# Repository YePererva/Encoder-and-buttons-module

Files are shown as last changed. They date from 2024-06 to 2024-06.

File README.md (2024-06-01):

# Rotary encoder and Push-Buttons module with hardware debouncing

Module provides rotary encoder and 3 push-buttons with debouncing circuitry, based on 74xx14 inverting Schmitt trigger.

## Dimensions and layout

- overall dimensions: 1.0 in × 2.5 in
- mounting holes spacing : 0.75 in × 2.25 in
- mounting holes size : M3
- SMD sized:
	- Resistors: 0805
	- Capacitors : 0805
	- Diodes : MiniMELF

| Top View | Bottom View |
| --- | ---|
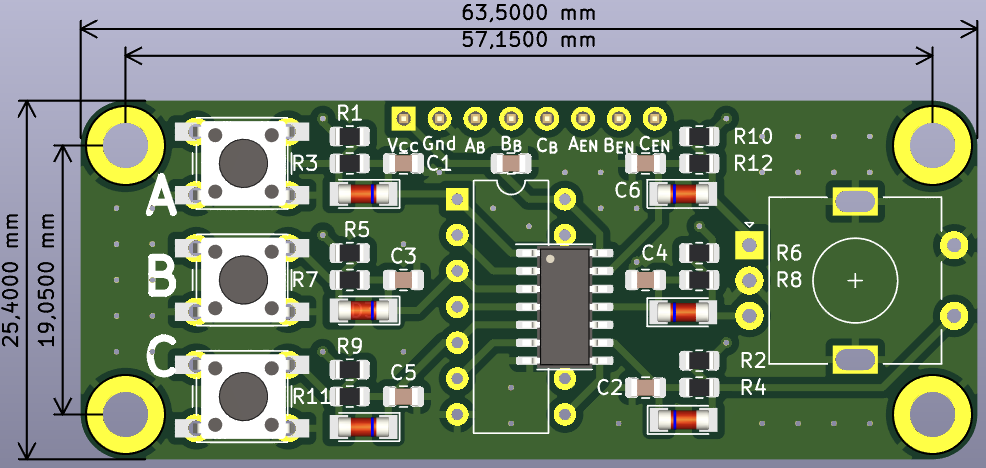
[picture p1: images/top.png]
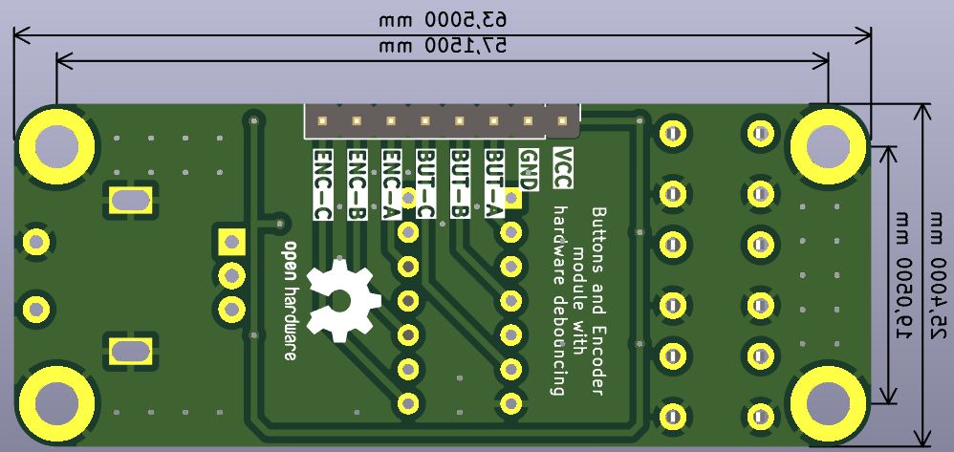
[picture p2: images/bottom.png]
|  |  |

## Schematics origin

Schematics is based on [this](https://my.eng.utah.edu/~cs5780/debouncing.pdf) work and is adjusted for:
- having both 1 rotary incremental encoder and 3 push buttons
- ability to solder eitehr SMD or DIP version of 74xx14 IC
- having option to push into breadboard or mount somewhere via mounting holes

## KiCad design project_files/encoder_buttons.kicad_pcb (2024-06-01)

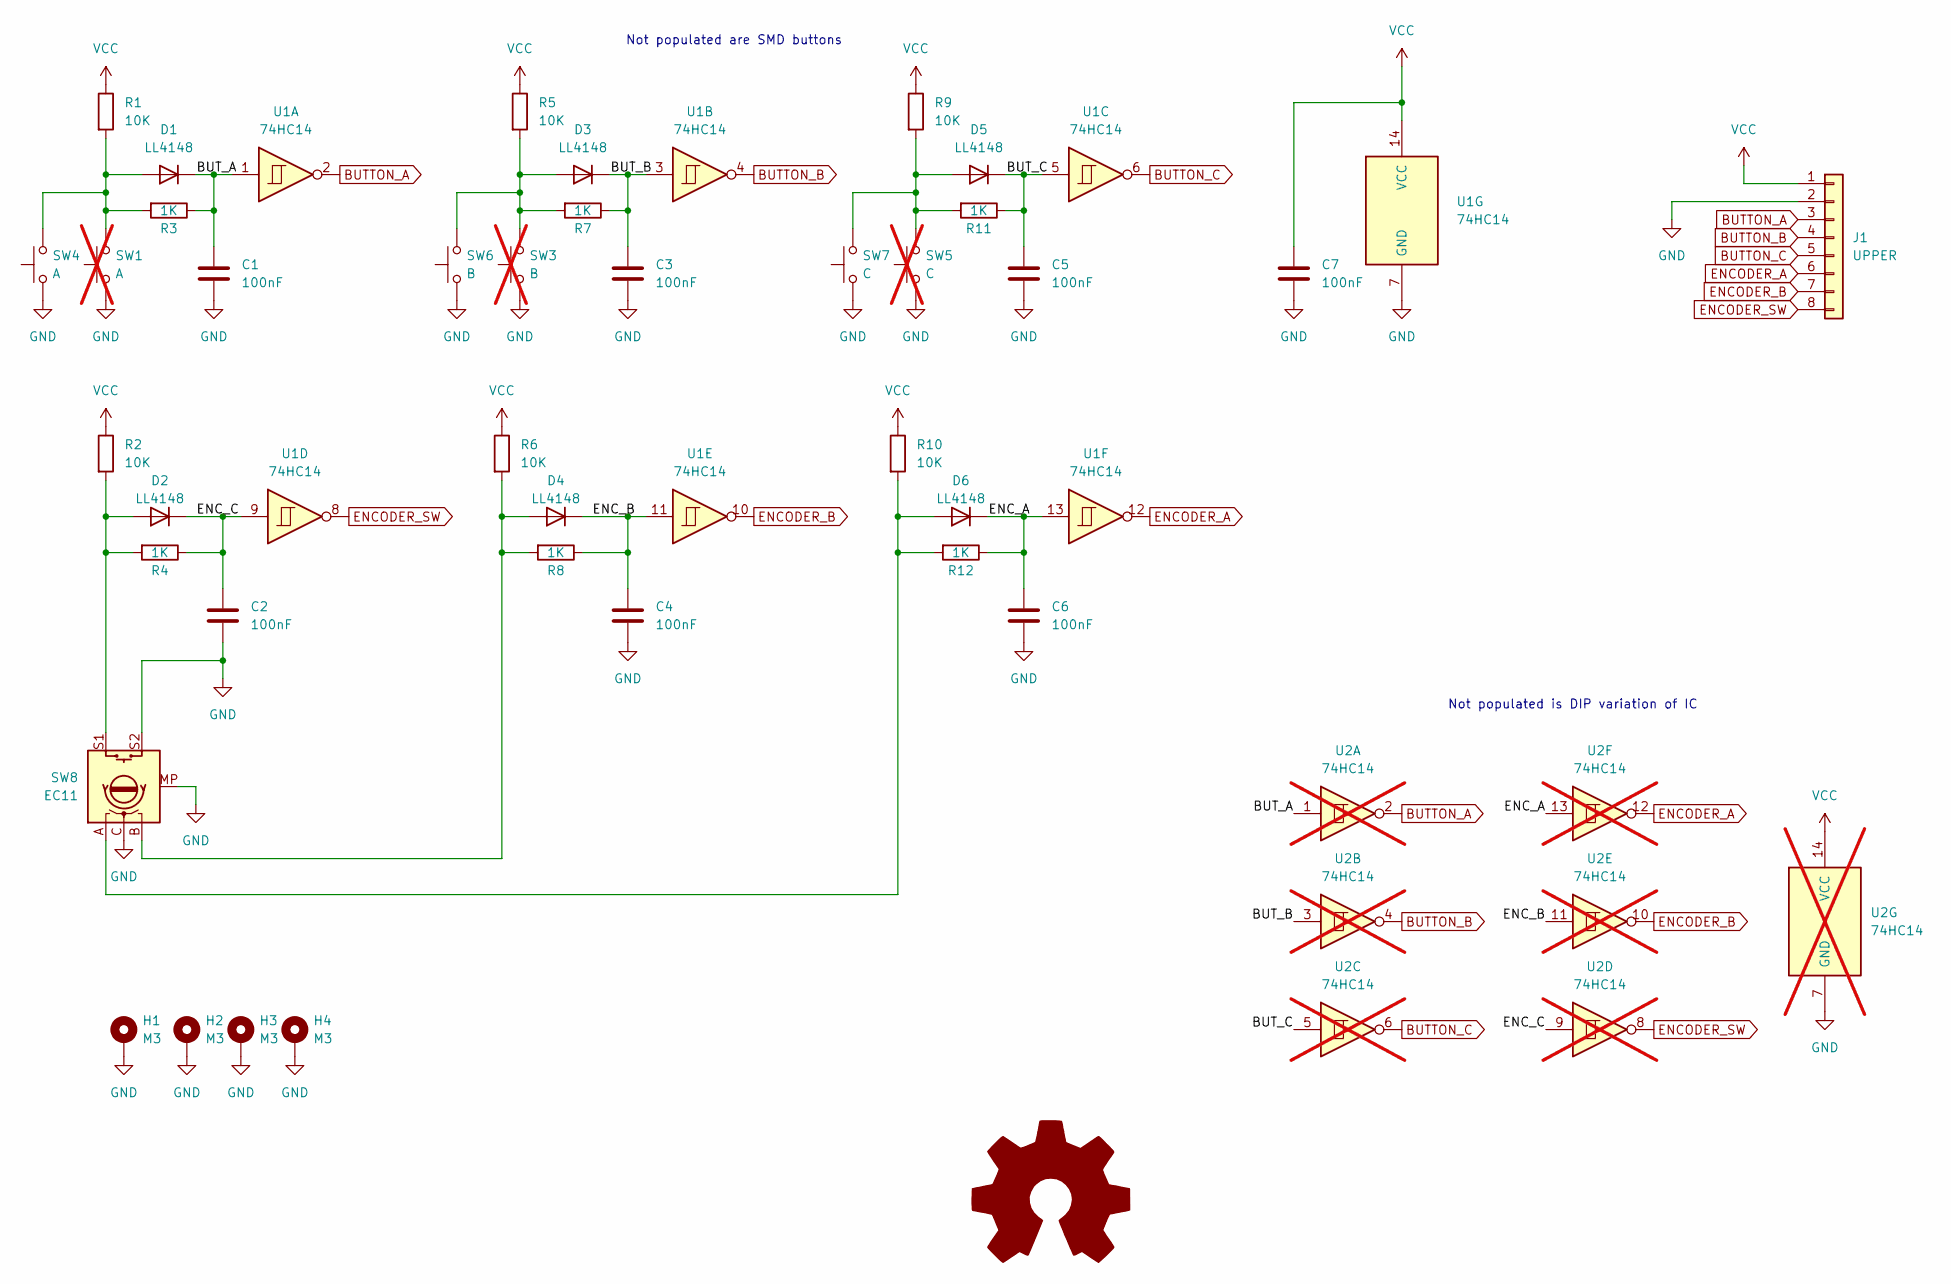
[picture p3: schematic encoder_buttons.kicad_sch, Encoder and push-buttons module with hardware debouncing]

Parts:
C1, C2, C3, C4, C5, C6, C7: 100nF; C_0805_2012Metric
D1, D2, D3, D4, D5, D6: LL4148; D_MiniMELF
H1, H2, H3, H4: M3; MountingHole_3.2mm_M3_DIN965_Pad_TopBottom
J1: UPPER; PinHeader_1x08_P2.54mm_Vertical
R1, R2, R5, R6, R9, R10: 10K; R_0805_2012Metric
R3, R4, R7, R8, R11, R12: 1K; R_0805_2012Metric
SW1: A; SW_SPST_PTS645; not fitted
SW3: B; SW_SPST_PTS645; not fitted
SW4: A; SW_PUSH_6mm
SW5: C; SW_SPST_PTS645; not fitted
SW6: B; SW_PUSH_6mm
SW7: C; SW_PUSH_6mm
SW8: EC11; RotaryEncoder_Alps_EC11E-Switch_Vertical_H20mm
U1: 74HC14; SO-14_3.9x8.65mm_P1.27mm
U2: 74HC14; DIP-14_W7.62mm; not fitted

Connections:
/BUT_A: C1.1, D1.1 (K), R3.1, U1.1, U2.1
/BUT_B: C3.1, D3.1 (K), R7.1, U1.3, U2.3
/BUT_C: C5.1, D5.1 (K), R11.1, U1.5, U2.5
/ENC_A: C6.1, D6.1 (K), R12.1, U1.13, U2.13
/ENC_B: C4.1, D4.1 (K), R8.1, U1.11, U2.11
/ENC_C: C2.1, D2.1 (K), R4.1, U1.9, U2.9
BUTTON_A: J1.3, U1.2, U2.2
BUTTON_B: J1.4, U1.4, U2.4
BUTTON_C: J1.5, U1.6, U2.6
ENCODER_A: J1.6, U1.12, U2.12
ENCODER_B: J1.7, U1.10, U2.10
ENCODER_SW: J1.8, U1.8, U2.8
GND: C1.2, C2.2, C3.2, C4.2, C5.2, C6.2, C7.2, H1.1, H2.1, H3.1, H4.1, J1.2, SW1.1, SW3.1, SW4.1, SW5.1, SW6.1, SW7.1, SW8.C, SW8.MP, SW8.S2, U1.7 (GND), U2.7 (GND)
unnamed: D1.2 (A), R1.2, R3.2, SW1.2, SW4.2
unnamed: D2.2 (A), R2.2, R4.2, SW8.S1
unnamed: D3.2 (A), R5.2, R7.2, SW3.2, SW6.2
unnamed: D4.2 (A), R6.2, R8.2, SW8.B
unnamed: D5.2 (A), R9.2, R11.2, SW5.2, SW7.2
unnamed: D6.2 (A), R10.2, R12.2, SW8.A
VCC: C7.1, J1.1, R1.1, R2.1, R5.1, R6.1, R9.1, R10.1, U1.14 (VCC), U2.14 (VCC)

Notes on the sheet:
Not populated is DIP variation of IC
Not populated are SMD buttons

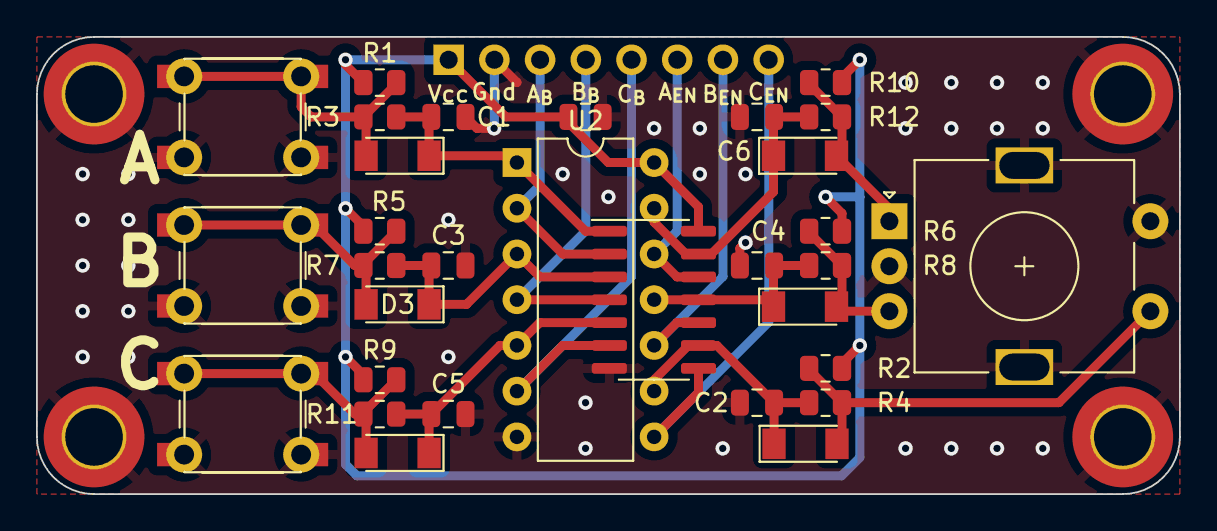
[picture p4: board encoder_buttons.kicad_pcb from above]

Board: 2 copper layers, 63.5 x 25.4 mm, 39 parts (1 on the bottom side), 20 nets.

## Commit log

2022-08-28 initial thoughts
    [encoder_buttons.kicad_pcb, encoder_buttons.kicad_sch]
2024-05-29 Reopened in Kicad 8
    [encoder_buttons.kicad_pcb, encoder_buttons.kicad_sch]
2024-05-29 placing the components
    [encoder_buttons.kicad_pcb, encoder_buttons.kicad_sch]
2024-05-29 minor edits
    [encoder_buttons.kicad_pcb]
2024-05-29 Finalized and rendered
    [encoder_buttons.kicad_pcb, encoder_buttons.kicad_sch]
2024-05-29 Added Readme and Dimensions
    [encoder_buttons.kicad_pcb]
2024-06-01 Re-routed with wider traces
    [encoder_buttons.kicad_pcb]
